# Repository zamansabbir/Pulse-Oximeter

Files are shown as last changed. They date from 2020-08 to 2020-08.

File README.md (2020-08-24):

# Pulse-Oximeter
This repository contains Firmware (driver) for PPG device made using PSOC1 chip to operate MAX30102 for collecting PPG signal and calculating SPO2. The device is dynamically tuned to address the technical reliability  issues involving PPG signal on people with dark skin tones.  

PPG_Firmware_6->Main.c files contains driver API for MAX30102

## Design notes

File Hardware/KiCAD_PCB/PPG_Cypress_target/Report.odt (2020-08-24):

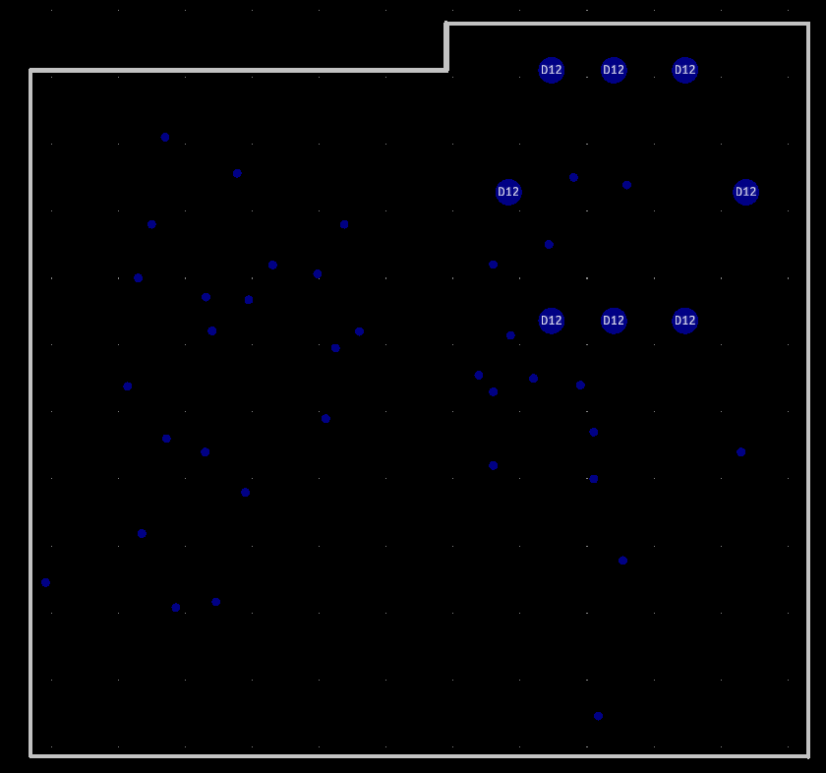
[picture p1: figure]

Fig: Drill with border line

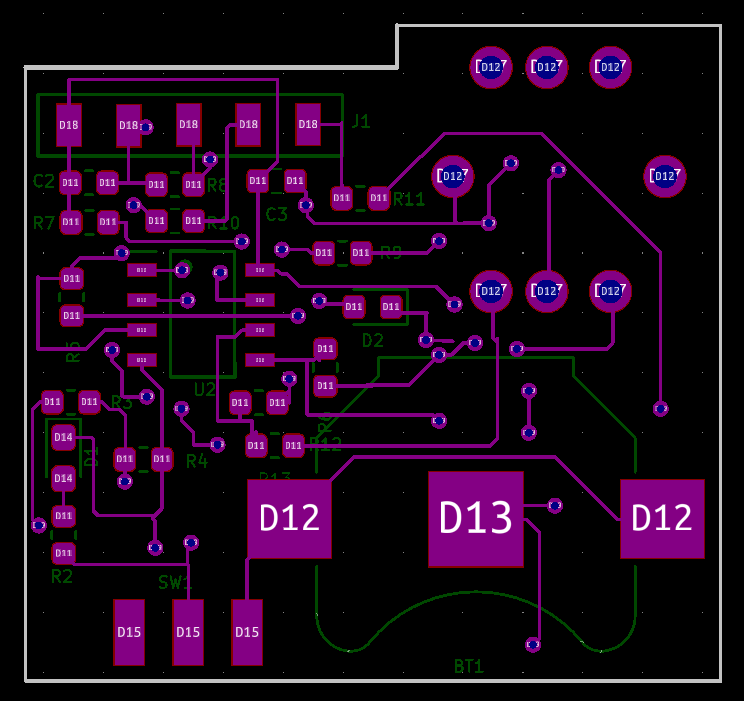
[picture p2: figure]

Top Layer

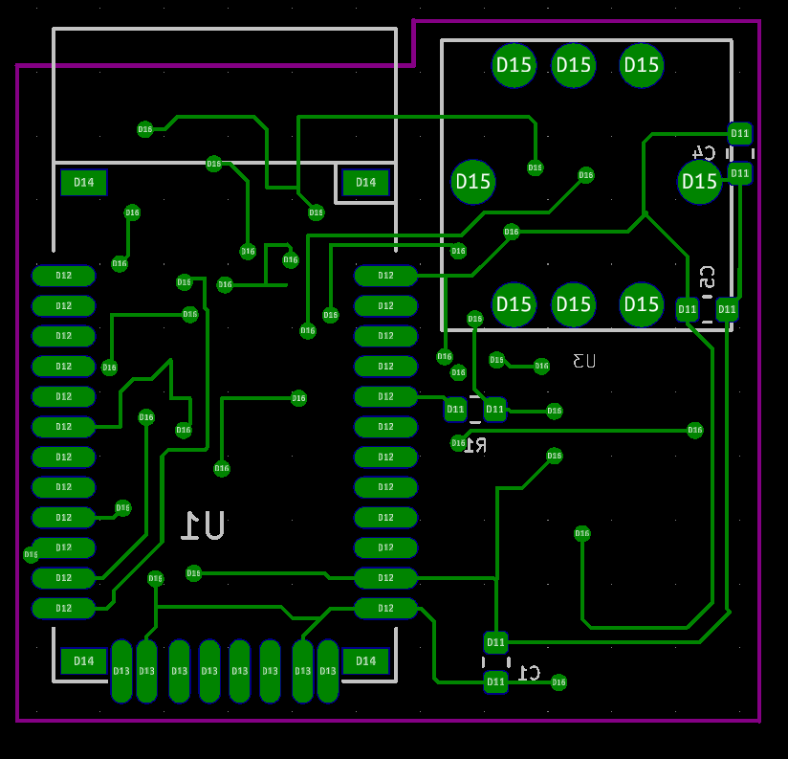
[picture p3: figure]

Bottom Layer

Application schematic of Max30102

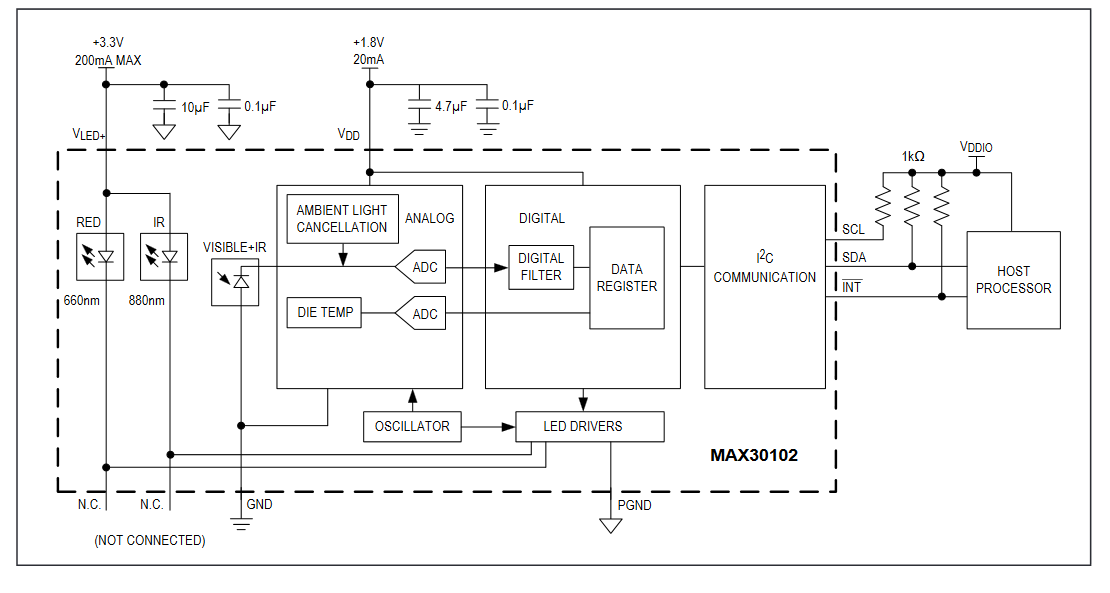
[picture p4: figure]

Schematic of Maxrefdes117

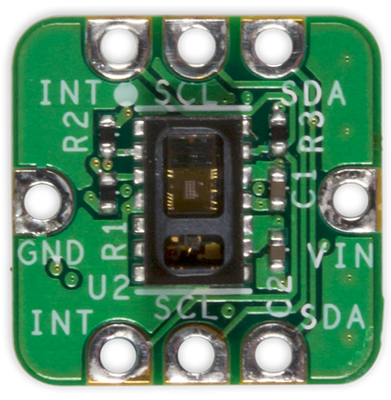
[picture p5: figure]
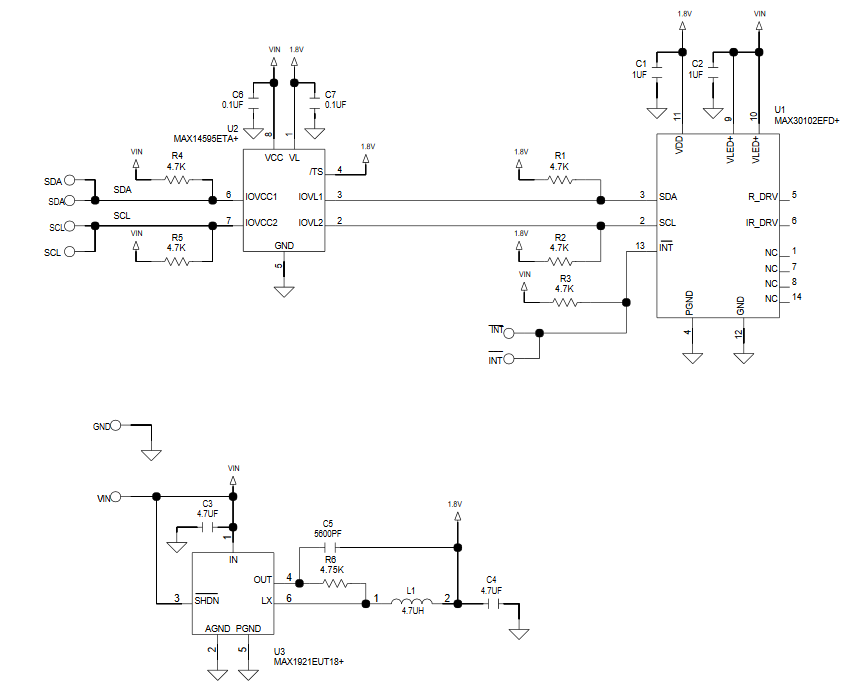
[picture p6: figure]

How to shutdown:

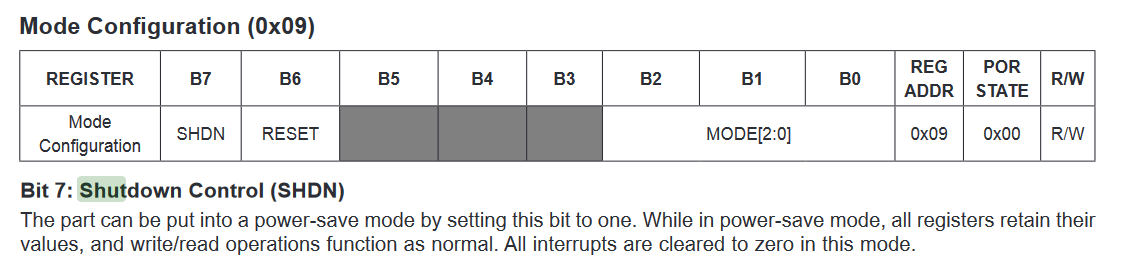
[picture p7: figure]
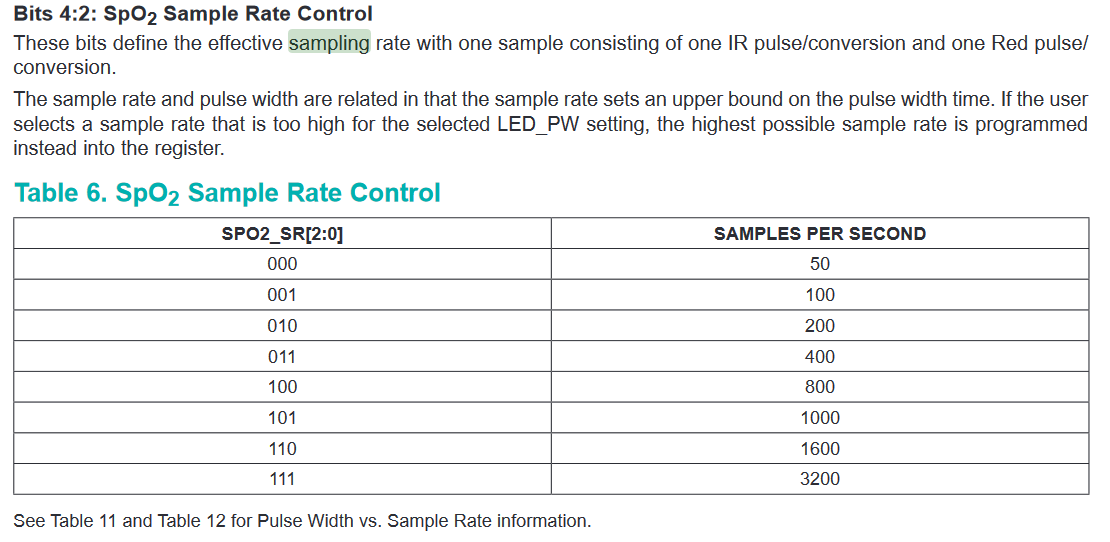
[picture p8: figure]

Sampling Rate control

ECG Annotation files are kept in Dropbox as pptx along with my annotation. For annotating with an expert

28 Excellent

30 Acceptable

30 Unacceptable

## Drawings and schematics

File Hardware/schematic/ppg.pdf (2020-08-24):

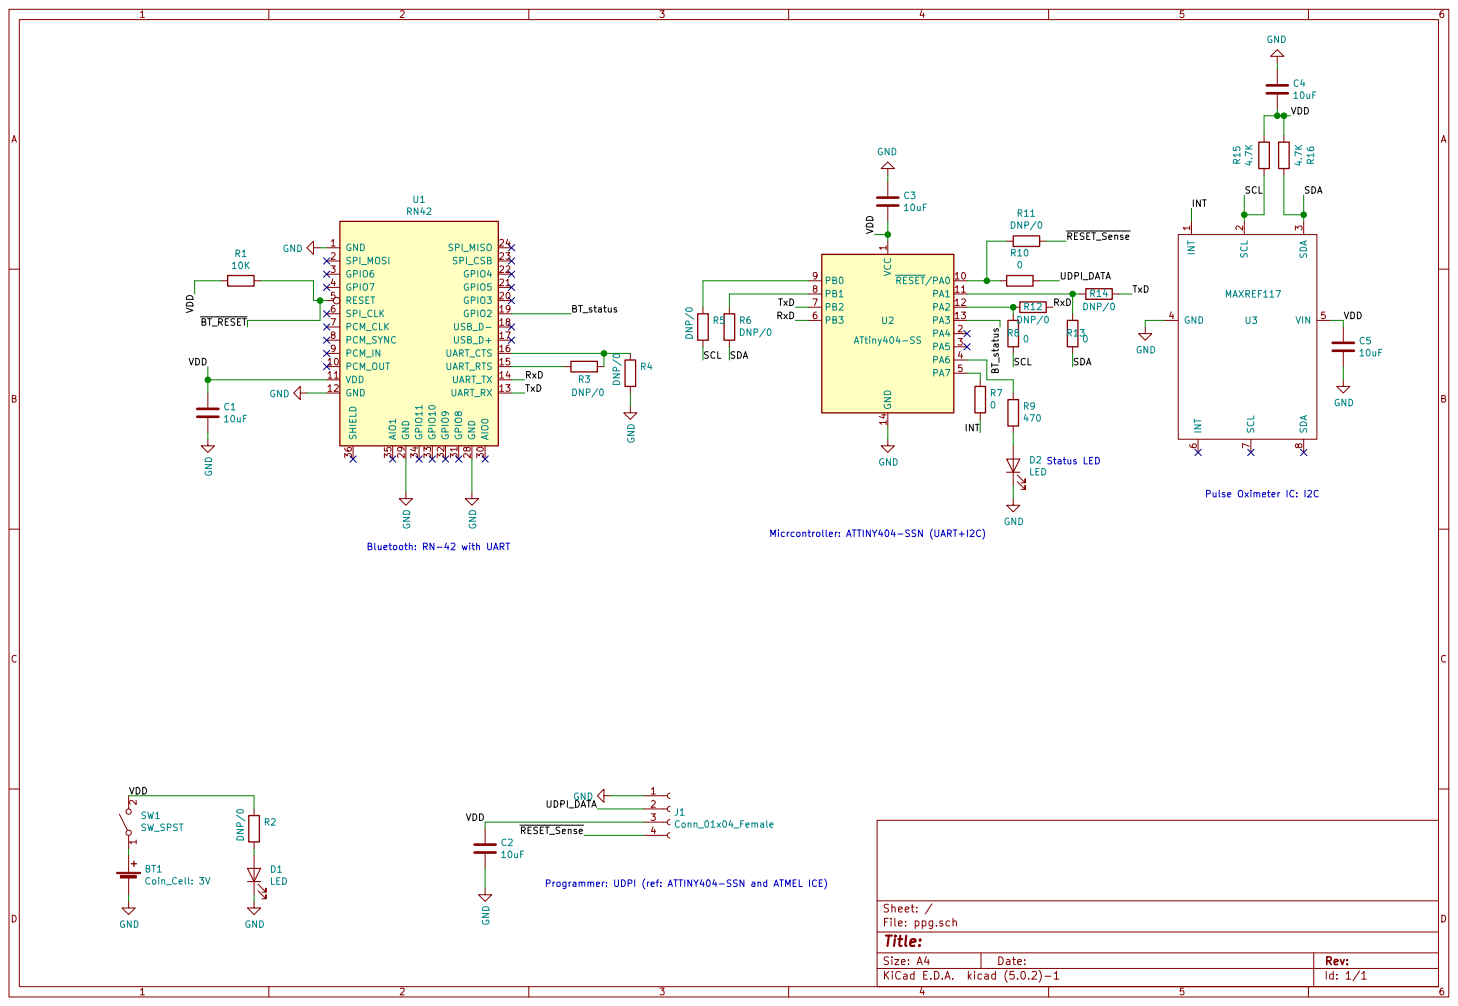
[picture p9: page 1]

10uF GND
File: ppg.sch Sheet: / VCC

1 RESET/PA0 10 PA1 11 PA2 12 PA3 13 GND 14 PA4 2 PA5 3 PA6 4 PA7 5 PB3 6 PB2 7 PB1 8 PB0 9 U2 ATtiny404-SS GND 1 PCM_OUT 10 VDD 11 GND 12 UART_RX 13 UART_TX 14 UART_RTS 15 UART_CTS 16 USB_D+ 17 USB_D- 18 GPIO2 19 SPI_MOSI 2 GPIO3 20 GPIO5 21 GPIO4 22 SPI_CSB 23 SPI_MISO 24 GND 28 GND 29 GPIO6 3 AIO0 30 GPIO8 31 GPIO9 32 GPIO10 33 GPIO11 34 AIO1 35 SHIELD 36 GPIO7 4 RESET 5 SPI_CLK 6 PCM_CLK 7 PCM_SYNC 8 PCM_IN 9 U1 RN42

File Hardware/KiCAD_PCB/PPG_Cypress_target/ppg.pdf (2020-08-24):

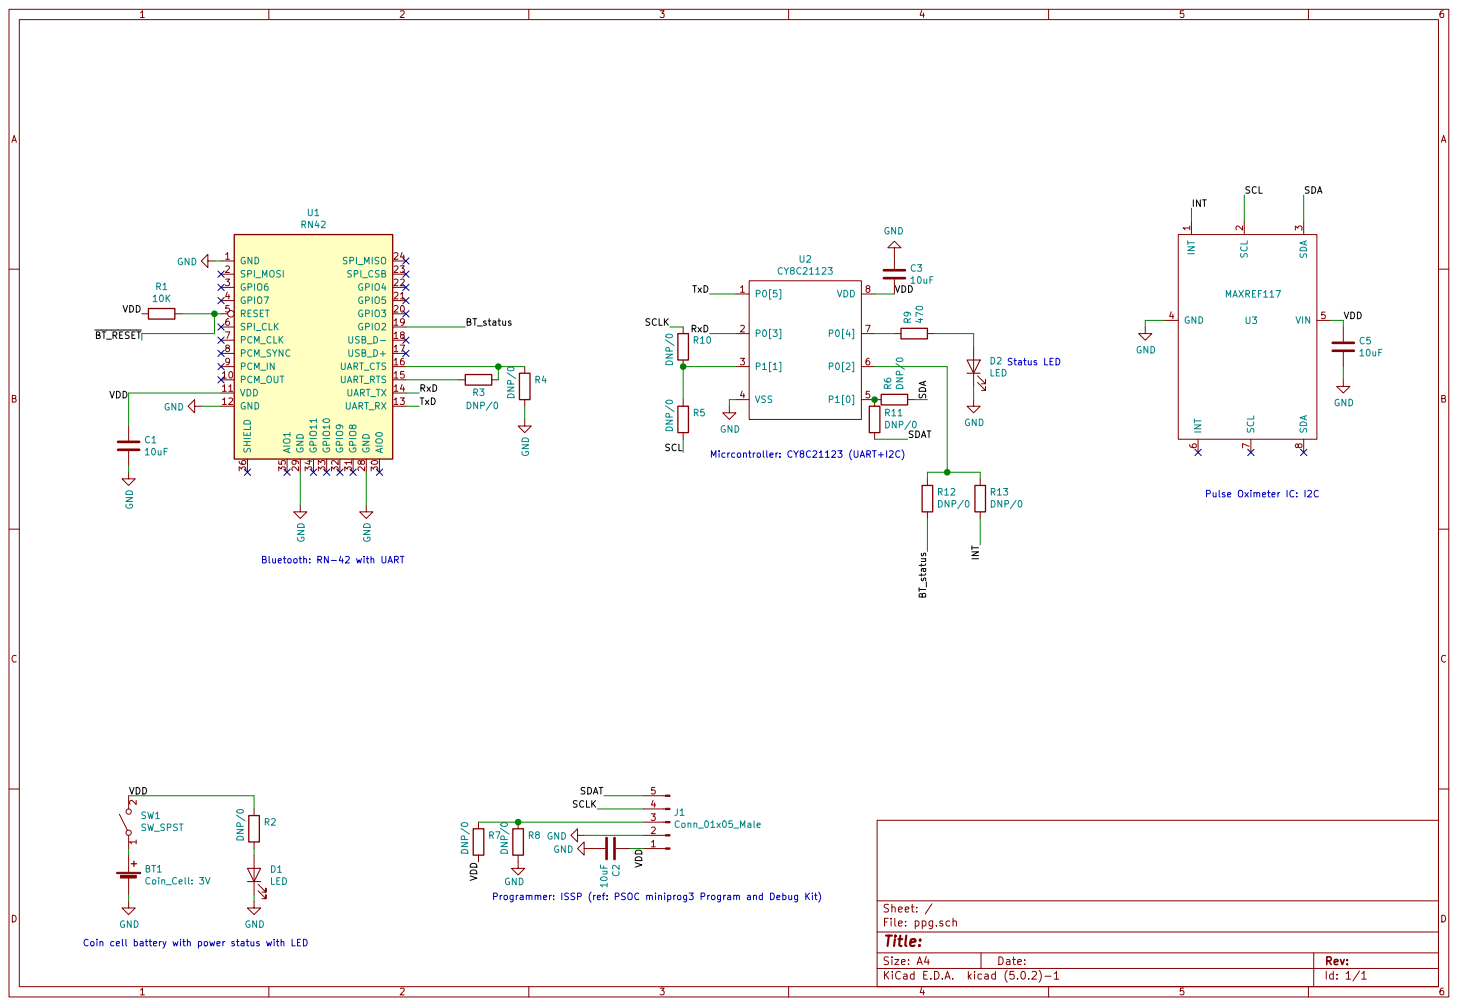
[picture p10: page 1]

File: ppg.sch Sheet: /
Id: 1/1 Title:

Coin cell battery with power status with LED

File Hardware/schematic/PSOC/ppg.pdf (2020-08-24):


File: ppg.sch Sheet: /
Id: 1/1 Title:

Coin cell battery with power status with LED

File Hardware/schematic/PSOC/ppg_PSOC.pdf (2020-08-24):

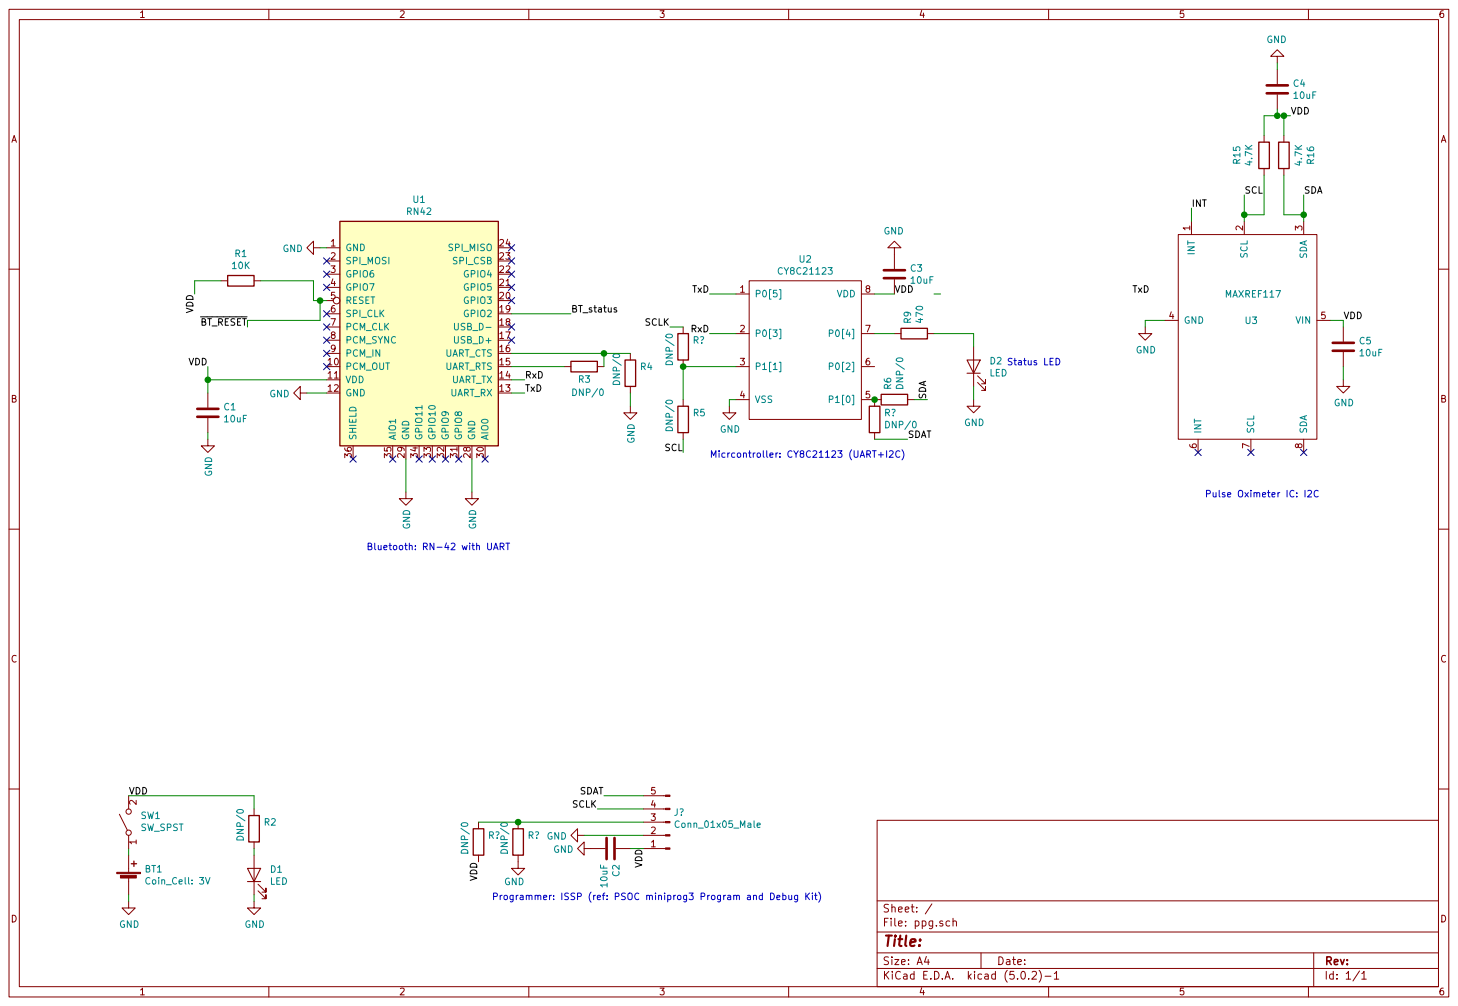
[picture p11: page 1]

File: ppg.sch Sheet: /
Id: 1/1 Title:

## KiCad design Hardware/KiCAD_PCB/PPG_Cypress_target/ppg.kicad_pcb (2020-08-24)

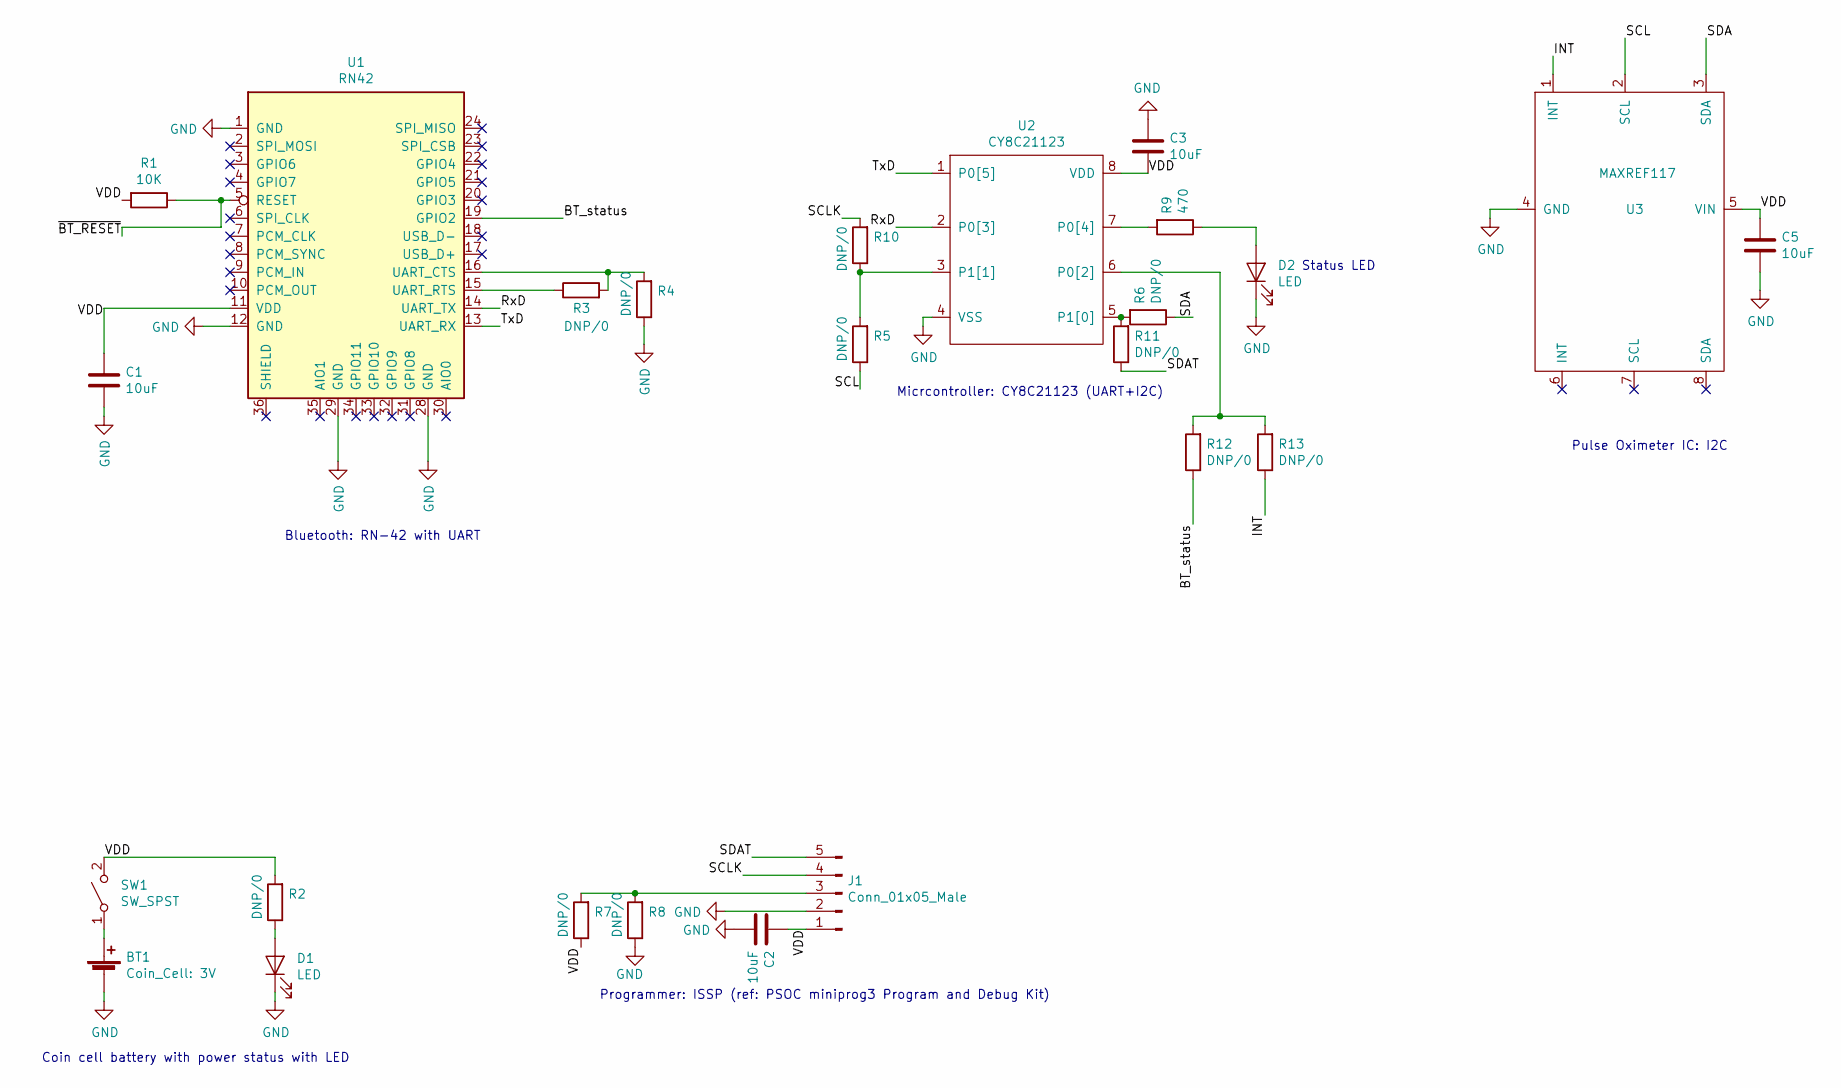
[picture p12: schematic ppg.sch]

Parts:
BT1: Coin_Cell: 3V; BatteryHolder_Keystone_3000_1x12mm
C1, C2, C3, C5: 10uF; C_0603_1608Metric
D1: LED; LED_0603_1608Metric_Pad1.05x0.95mm_HandSolder
D2: LED; LED_0603_1608Metric
J1: Conn_01x05_Male; Cypress_Programmer
R1: 10K; R_0603_1608Metric
R2, R3, R4, R5, R6, R7, R8, R10, R11, R12, R13: DNP/0; R_0603_1608Metric
R9: 470; R_0603_1608Metric
SW1: SW_SPST; Slide_SPDT_CK-JS102011SAQN
U1: RN42; RN42_v2
U2: CY8C21123; CY8C21123_8_SOIC
U3: MAXREF117; Pulse_Oximeter

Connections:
/BT_status: R12.1, U1.19 (GPIO2)
/INT: R13.1, U3.1 (INT)
/RxD: U1.14 (UART_TX), U2.2 (P0[3])
/SCL: R5.1, U3.2 (SCL)
/SCLK: J1.4, R10.2
/SDA: R6.1, U3.3 (SDA)
/SDAT: J1.5, R11.1
/TxD: U1.13 (UART_RX), U2.1 (P0[5])
/VDD: C1.1, C2.1, C3.2, C5.1, J1.1, R1.2, R2.2, R7.1, SW1.2 (B), U1.11 (VDD), U2.8 (VDD), U3.5 (VIN); also elsewhere on the board
/~BT_RESET: R1.1, U1.5 (RESET)
GND: BT1.2 (-), C1.2, C2.2, C3.1, C5.2, D1.1 (K), D2.1 (K), J1.2, R4.1, R8.1, U1.1 (GND), U1.12 (GND), U1.28 (GND), U1.29 (GND), U2.4 (VSS), U3.4 (GND); also elsewhere on the board
unnamed: BT1.1 (+), SW1.1 (A)
unnamed: D1.2 (A), R2.1
unnamed: D2.2 (A), R9.1
unnamed: J1.3, R7.2, R8.2
unnamed: R3.1, U1.15 (UART_RTS)
unnamed: R3.2, R4.2, U1.16 (UART_CTS)
unnamed: R9.2, U2.7 (P0[4])
unnamed: R5.2, R10.1, U2.3 (P1[1])
unnamed: R6.2, R11.2, U2.5 (P1[0])
unnamed: R12.2, R13.2, U2.6 (P0[2])

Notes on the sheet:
Programmer: ISSP (ref: PSOC miniprog3 Program and Debug Kit)
Bluetooth: RN-42 with UART
Micrcontroller: CY8C21123 (UART+I2C)
Status LED
Pulse Oximeter IC: I2C
Coin cell battery with power status with LED

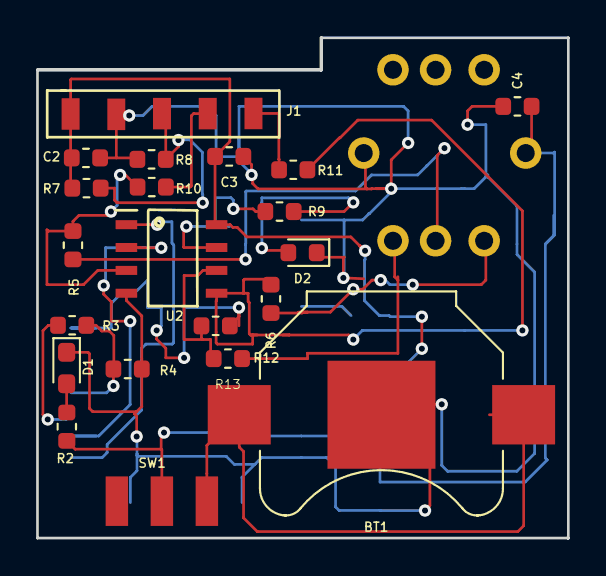
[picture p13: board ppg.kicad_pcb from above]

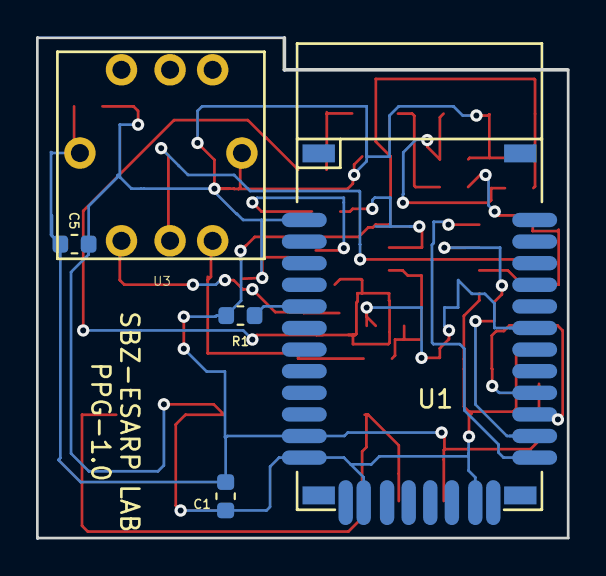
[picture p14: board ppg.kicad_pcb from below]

Board: 2 copper layers, 29.5 x 27.8 mm, 26 parts (5 on the bottom side), 21 nets.

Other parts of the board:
C4: 10uF; C_0603_1608Metric

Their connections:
/VDD: C4.2; also elsewhere on the board
GND: C4.1; also elsewhere on the board

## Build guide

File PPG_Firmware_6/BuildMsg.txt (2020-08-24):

Starting MAKE...
creating project.mk 

lib/i2chwcommon.asm

lib/i2chwint.asm

lib/i2chwmstr.asm

lib/i2chwrsrcinits.asm

lib/psocconfig.asm

lib/psocconfigtbl.asm

lib/uart.asm

lib/uartint.asm

lib/uartplus.asm

./boot.asm

Linking..

  ROM 56% full. 2266 out of 4096 bytes used (does not include absolute areas).

  RAM 11% full. 27 bytes used (does not include stack usage).

Built with ICCM8C STD V7.05.00

PPG_Firmware_6 - 0 error(s) 0 warning(s) 18:04:45

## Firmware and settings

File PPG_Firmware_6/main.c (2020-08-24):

//----------------------------------------------------------------------------
// C main line
//----------------------------------------------------------------------------


#include <m8c.h>        // part specific constants and macros
#include "PSoCAPI.h"    // PSoC API definitions for all User Modules
#include "delay.h"




#define I2C_DEV_ADDRESS 0x57 //Taking higher 7-bits from 0xAE. .automatically changes the address to 0xAE with read or write bit addition by the read write functions

//register addresses
#define REG_INTR_STATUS_1 0x00
#define REG_INTR_STATUS_2 0x01
#define REG_INTR_ENABLE_1 0x02
#define REG_INTR_ENABLE_2 0x03
#define REG_FIFO_WR_PTR 0x04
#define REG_OVF_COUNTER 0x05
#define REG_FIFO_RD_PTR 0x06
#define REG_FIFO_DATA 0x07
#define REG_FIFO_CONFIG 0x08
#define REG_MODE_CONFIG 0x09
#define REG_SPO2_CONFIG 0x0A
#define REG_LED1_PA 0x0C
#define REG_LED2_PA 0x0D
#define REG_PILOT_PA 0x10
#define REG_MULTI_LED_CTRL1 0x11
#define REG_MULTI_LED_CTRL2 0x12
#define REG_TEMP_INTR 0x1F
#define REG_TEMP_FRAC 0x20
#define REG_TEMP_CONFIG 0x21
#define REG_PROX_INT_THRESH 0x30
#define REG_REV_ID 0xFE
#define REG_PART_ID 0xFF

void i2c_init(void){
	I2CHW_Start();
	I2CHW_EnableMstr();
	I2CHW_EnableInt();
	
}

/**
*\ This function writes the content of a particular registers
*\ parameter addr		-Register address
*\parameter data		-the content to be written in the register
*\return value			-None
*/
void PO_HR_Sensor_write_reg(BYTE addr, BYTE data){
	I2CHW_fSendStart(I2C_DEV_ADDRESS, I2CHW_WRITE);
	I2CHW_fWrite(addr);
	I2CHW_fWrite(data);
	I2CHW_SendStop();
	//adding extra for caution, if does not work, remove it
	while (!(I2CHW_bReadBusStatus()&I2CHW_WR_COMPLETE));
	I2CHW_ClrWrStatus();
}

/**
*\ This function reads the content of a particular registers
*\ parameter addr	-Register address
*\return value		-the content of the register
*/
BYTE PO_HR_Sensor_read_reg(BYTE addr){
	BYTE data;
	I2CHW_fSendStart(I2C_DEV_ADDRESS, I2CHW_WRITE);
	I2CHW_fWrite(addr);
	I2CHW_fSendRepeatStart(I2C_DEV_ADDRESS,I2CHW_READ);
	data=I2CHW_bRead(I2CHW_NAKslave); //send NAK 
	I2CHW_SendStop();
		//adding extra for caution, if does not work, remove it
	//while (!(I2CHW_bReadBusStatus()&I2CHW_RD_COMPLETE));
	//I2CHW_ClrRdStatus();
	return data;
}

/**
*\ This function initializes the Pulse oximeter and Heart Rate Sensor with the initial value
*\ parameter 		-None
*\return value		-None
*/
void PO_HR_Sensor_init(void){

	PO_HR_Sensor_write_reg(REG_INTR_ENABLE_1,0xc0);	//INTR setting
	PO_HR_Sensor_write_reg(REG_INTR_ENABLE_2,0x00); //INTR setting
	PO_HR_Sensor_write_reg(REG_FIFO_WR_PTR,0x00);//FIFO_WR_PTR
	PO_HR_Sensor_write_reg(REG_OVF_COUNTER,0x00);//OVF_Counter
	PO_HR_Sensor_write_reg(REG_FIFO_RD_PTR,0x00);//FIFO_RD_PTR
	PO_HR_Sensor_write_reg(REG_FIFO_CONFIG,0x0f);//sample average=4(010), fifo rollover=false, fifo almost full=17, now sample average=1
	PO_HR_Sensor_write_reg(REG_MODE_CONFIG,0x03); //0x02 for red only, 0x03 for spo2 mode, 0x07 multimode LED
	PO_HR_Sensor_write_reg(REG_SPO2_CONFIG,0x47); // SPO2_ADC range=8192 nA, SPO2 sampling rate 100 Hz, pulse width of LED= 411uS
	PO_HR_Sensor_write_reg(REG_LED1_PA,0x32); //LED 1=7mA (0x24),0x3F=12.6mA,0x32=10mA 
	PO_HR_Sensor_write_reg(REG_LED2_PA,0x32);//LED 2=7mA(0x24),0x3F=12.6mA,0x32=10mA
	//PO_HR_Sensor_write_reg(REG_PILOT_PA,0x7f);//Pilot LED =25mA
	
}
/**
*\ This function resets the Pulse oximeter and Heart Rate Sensor 
*\ parameter 		-None
*\return value		-None
*/
void  PO_HR_Sensor_reset(void){
	PO_HR_Sensor_write_reg(REG_MODE_CONFIG,0x40);
	
}


/**
*\ This function reads 6 bytes of sample data from FIFO_DATA. 3 bytes for IR channel and 3 bytes for Red channel
*\ parameter none
*/
void PO_HR_Sensor_read_fifo(void){

	//INT IR_Channel=0,RED_Channel=0,temp=0;
	BYTE RED_Channel1,RED_Channel2,RED_Channel3,IR_Channel1,IR_Channel2,IR_Channel3;
 	BYTE uch_temp;
  	uch_temp=PO_HR_Sensor_read_reg(REG_INTR_STATUS_1);
 	uch_temp=PO_HR_Sensor_read_reg(REG_INTR_STATUS_2);
	
  	I2CHW_fSendStart(I2C_DEV_ADDRESS, I2CHW_WRITE);
  	I2CHW_fWrite(REG_FIFO_DATA);
	I2CHW_fSendRepeatStart(I2C_DEV_ADDRESS,I2CHW_READ);

	
	RED_Channel1=I2CHW_bRead(I2CHW_ACKslave);

	RED_Channel2=I2CHW_bRead(I2CHW_ACKslave);

	RED_Channel3=I2CHW_bRead(I2CHW_ACKslave);

	IR_Channel1=I2CHW_bRead(I2CHW_ACKslave);

	IR_Channel2=I2CHW_bRead(I2CHW_ACKslave);

	IR_Channel3=I2CHW_bRead(I2CHW_NAKslave);
	I2CHW_SendStop();

	UART_PutChar('R');
	UART_PutChar(RED_Channel1);
	UART_PutChar(RED_Channel2);
	UART_PutChar(RED_Channel3);
	
	UART_PutChar('I');
	UART_PutChar(IR_Channel1);
	UART_PutChar(IR_Channel2);
	UART_PutChar(IR_Channel3);
	}

void blink(void){

		//UART_PutChar('1');
		LED_Data_ADDR&=~LED_MASK;
		Delay10msTimes(50);
		//UART_PutChar('0');
		LED_Data_ADDR|=LED_MASK;
		Delay10msTimes(50);

}
void main(void)
{	
	//INT i=0x1234;
	BYTE i=0;
	 M8C_EnableGInt ; // Uncomment this line to enable Global Interrupts
	// Insert your main routine code here.
	i2c_init();
	
	UART_Start(UART_PARITY_NONE);
	PO_HR_Sensor_reset();	 	
	Delay10msTimes(50);
	PO_HR_Sensor_init(); 
	for (i=0;i<10;i++){
		blink();
	}
	LED_Data_ADDR&=~LED_MASK;
	while (1){

		while ((INT_Pin_Data_ADDR&INT_Pin_MASK)){
		;
		}
			PO_HR_Sensor_read_fifo();
	
	}
	
}

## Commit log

2020-08-24 Firmware and Hardware(KiCAD project) added
2020-08-24 PPG firmware and hardware files are added
    [ppg-B.Cu.gbl, ppg-B.Mask.gbs, ppg-B.SilkS.gbo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]
